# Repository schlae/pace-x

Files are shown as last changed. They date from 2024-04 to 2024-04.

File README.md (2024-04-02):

# Pace-X INS8900 Computer

(Still under development)

The INS8900 is a NMOS version of National Semiconductor's PACE microprocessor.
This was (probably) the first 16-bit microprocessor to hit the market in the
mid 1970s.

This is a very simple computer built around this chip. Features include

* 2MHz operation
* 128K words of RAM
* Up to 128K words of ROM
* 8250 (or compatible) UART
* Software controlled status LEDs
* 12VDC input

Note that the memory split between RROM and RAM is controlled by a PAL that
sets up the memory map. Banking is supported using up to three flag outputs
(F11, F12, F13) on the CPU. The current memory map is:

* 0000 to 001FF - ROM (can be swapped out with RAM using F11)
* 0200 to FDFF - RAM
* FE00 to FFFF - UART (mirrored a bunch of times)

UART access is easiest at FF00 (absolute). But it can also be done from the
zero page when BPS is brought high. This can be activated using F12.

The PAL code is assembled using `galette`. [site](https://github.com/simon-frankau/galette)

The assembly code for the INS8900 is assembled using `asl` [site]([http://john.ccac.rwth-aachen.de:8000/as/)

## Assembling the code

CPU source code is assembled as follows

```
asl test.asm -L
p2bin test.p test.bin
python3 split.py
```

The result are two files, `high.bin` and `low.bin` which need to be programmed
into two EPROMS or EEPROMS. You can do this with a TL866 using `minipro`. For example, using two MX28F1000P EEPROM chips:

```
minipro -p MX28F1000P -w low.bin -s
```
(swap the chips)
```
minipro -p MX28F1000P -w high.bin -s
```

To assemble and program the GAL, run
```
galette addr_decoder.pld
minipro -p ATF16V8B -w addr_decoder.jed
```

That's all for now!

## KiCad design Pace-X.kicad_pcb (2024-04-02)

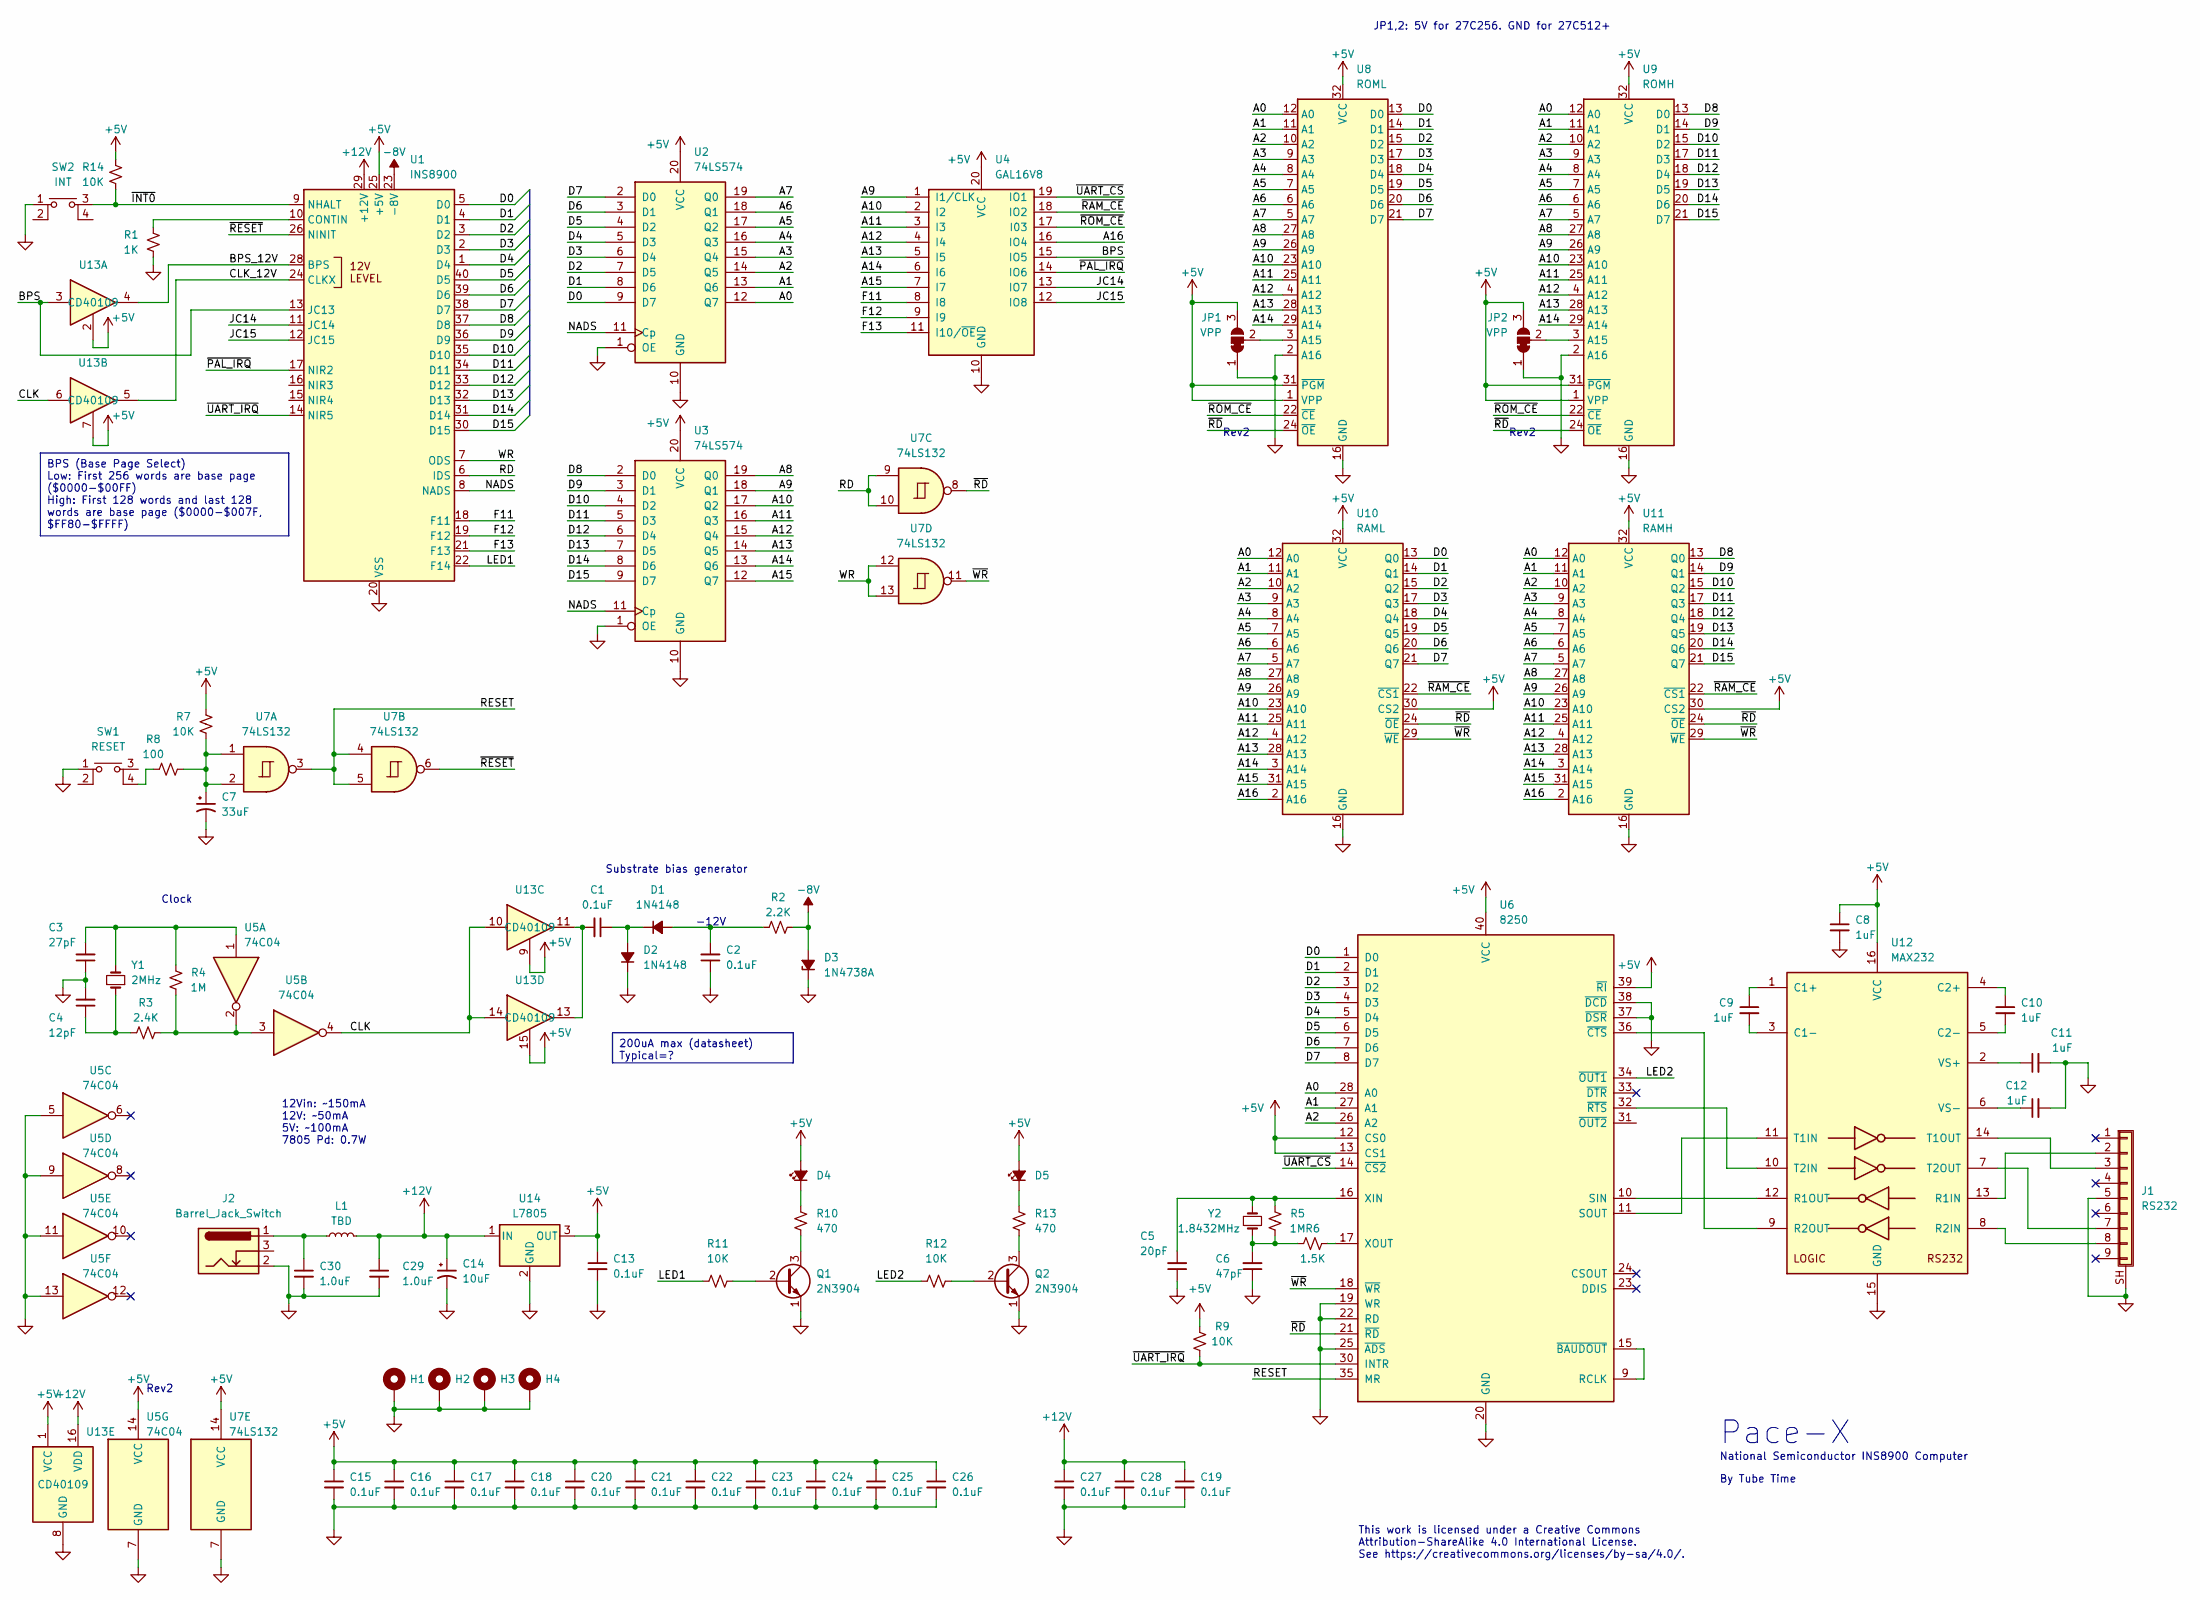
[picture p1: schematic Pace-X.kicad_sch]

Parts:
C1, C2, C13, C15, C16, C17, C18, C19, C20, C21, C22, C23, C24, C25, C26, C27, C28: 0.1uF; CAPAC200
C3: 27pF; CAPAC200
C4: 12pF; CAPAC200
C5: 20pF; CAPAC200
C6: 47pF; CAPAC200
C7: 33uF; CAPAE200P500X1100
C8, C9, C10, C11, C12: 1uF; CAPAC200
C14: 10uF; CAPAE200P500X1100
C29, C30: 1.0uF; CAPAC200
D1, D2: 1N4148; DIOA500
D3: 1N4738A; DIOA500
D4, D5: LED; LED_D5.0mm
H1, H2, H3, H4: MountingHole_Pad; MountingHole_3.2mm_M3_ISO7380_Pad
J1: RS232; DB9FC2
J2: Barrel_Jack_Switch; CUI_PJ-002B
JP1, JP2: VPP; SolderJumper-3_P1.3mm_Bridged12_RoundedPad1.0x1.5mm_NumberL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
L1: TBD; L_Axial_L7.0mm_D3.3mm_P12.70mm_Horizontal_Fastron_MICC
Q1, Q2: 2N3904; TO-92_Inline
R1: 1K; RESA500
R2: 2.2K; RESA500
R3: 2.4K; RESA500
R4, R5: 1M; RESA500
R6: 1.5K; RESA500
R7, R9, R11, R12, R14: 10K; RESA500
R8: 100; RESA500
R10, R13: 470; RESA500
SW1: RESET; ESWITCH_TL1105
SW2: INT; ESWITCH_TL1105
U1: INS8900; DIP254P1524X635-40
U2, U3: 74LS574; DIP254P762X635-20
U4: GAL16V8; DIP254P762X635-20
U5: 74C04; DIP254P762X635-14
U6: 8250; DIP254P1524X635-40
U7: 74LS132; DIP254P762X635-14
U8: ROML; DIP254P1524X635-32
U9: ROMH; DIP254P1524X635-32
U10: RAML; DIP254P1524X635-32
U11: RAMH; DIP254P1524X635-32
U12: MAX232; DIP254P762X635-16
U13: CD40109; DIP254P762X635-16
U14: L7805; TO-220-3_Horizontal_TabDown
Y1: 2MHz; Crystal_HC49-U_Vertical
Y2: 1.8432MHz; Crystal_HC49-U_Vertical

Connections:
-8V: D3.2 (A), R2.2, U1.23 (-8V)
/A0: U2.12 (Q7), U6.28 (A0), U8.12 (A0), U9.12 (A0), U10.12 (A0), U11.12 (A0)
/A1: U2.13 (Q6), U6.27 (A1), U8.11 (A1), U9.11 (A1), U10.11 (A1), U11.11 (A1)
/A2: U2.14 (Q5), U6.26 (A2), U8.10 (A2), U9.10 (A2), U10.10 (A2), U11.10 (A2)
/A3: U2.15 (Q4), U8.9 (A3), U9.9 (A3), U10.9 (A3), U11.9 (A3)
/A4: U2.16 (Q3), U8.8 (A4), U9.8 (A4), U10.8 (A4), U11.8 (A4)
/A5: U2.17 (Q2), U8.7 (A5), U9.7 (A5), U10.7 (A5), U11.7 (A5)
/A6: U2.18 (Q1), U8.6 (A6), U9.6 (A6), U10.6 (A6), U11.6 (A6)
/A7: U2.19 (Q0), U8.5 (A7), U9.5 (A7), U10.5 (A7), U11.5 (A7)
/A8: U3.19 (Q0), U8.27 (A8), U9.27 (A8), U10.27 (A8), U11.27 (A8)
/A9: U3.18 (Q1), U4.1 (I1/CLK), U8.26 (A9), U9.26 (A9), U10.26 (A9), U11.26 (A9)
/A10: U3.17 (Q2), U4.2 (I2), U8.23 (A10), U9.23 (A10), U10.23 (A10), U11.23 (A10)
/A11: U3.16 (Q3), U4.3 (I3), U8.25 (A11), U9.25 (A11), U10.25 (A11), U11.25 (A11)
/A12: U3.15 (Q4), U4.4 (I4), U8.4 (A12), U9.4 (A12), U10.4 (A12), U11.4 (A12)
/A13: U3.14 (Q5), U4.5 (I5), U8.28 (A13), U9.28 (A13), U10.28 (A13), U11.28 (A13)
/A14: U3.13 (Q6), U4.6 (I6), U8.29 (A14), U9.29 (A14), U10.3 (A14), U11.3 (A14)
/A15: U3.12 (Q7), U4.7 (I7), U10.31 (A15), U11.31 (A15)
/A16: U4.16 (IO4), U10.2 (A16), U11.2 (A16)
/BPS: U1.13 (JC13), U4.15 (IO5), U13.3
/BPS_12V: U1.28 (BPS), U13.4
/CLK: U5.4, U13.6, U13.10, U13.14
/CLK_12V: U1.24 (CLKX), U13.5
/D0: U1.5 (D0), U2.9 (D7), U6.1 (D0), U8.13 (D0), U10.13 (Q0)
/D1: U1.4 (D1), U2.8 (D6), U6.2 (D1), U8.14 (D1), U10.14 (Q1)
/D2: U1.3 (D2), U2.7 (D5), U6.3 (D2), U8.15 (D2), U10.15 (Q2)
/D3: U1.2 (D3), U2.6 (D4), U6.4 (D3), U8.17 (D3), U10.17 (Q3)
/D4: U1.1 (D4), U2.5 (D3), U6.5 (D4), U8.18 (D4), U10.18 (Q4)
/D5: U1.40 (D5), U2.4 (D2), U6.6 (D5), U8.19 (D5), U10.19 (Q5)
/D6: U1.39 (D6), U2.3 (D1), U6.7 (D6), U8.20 (D6), U10.20 (Q6)
/D7: U1.38 (D7), U2.2 (D0), U6.8 (D7), U8.21 (D7), U10.21 (Q7)
/D8: U1.37 (D8), U3.2 (D0), U9.13 (D0), U11.13 (Q0)
/D9: U1.36 (D9), U3.3 (D1), U9.14 (D1), U11.14 (Q1)
/D10: U1.35 (D10), U3.4 (D2), U9.15 (D2), U11.15 (Q2)
/D11: U1.34 (D11), U3.5 (D3), U9.17 (D3), U11.17 (Q3)
/D12: U1.33 (D12), U3.6 (D4), U9.18 (D4), U11.18 (Q4)
/D13: U1.32 (D13), U3.7 (D5), U9.19 (D5), U11.19 (Q5)
/D14: U1.31 (D14), U3.8 (D6), U9.20 (D6), U11.20 (Q6)
/D15: U1.30 (D15), U3.9 (D7), U9.21 (D7), U11.21 (Q7)
/F11: U1.18 (F11), U4.8 (I8)
/F12: U1.19 (F12), U4.9 (I9)
/F13: U1.21 (F13), U4.11 (I10/~OE)
/JC14: U1.11 (JC14), U4.13 (IO7)
/JC15: U1.12 (JC15), U4.12 (IO8)
/LED1: R11.2, U1.22 (F14)
/LED2: R12.2, U6.34 (~OUT1)
/NADS: U1.8 (NADS), U2.11 (Cp), U3.11 (Cp)
/RD: U1.6 (IDS), U7.9, U7.10
/RESET: U6.35 (MR), U7.3, U7.4, U7.5
/WR: U1.7 (ODS), U7.12, U7.13
/~INT0: R14.1, SW2.3, U1.9 (NHALT)
/~PAL_IRQ: U1.17 (NIR2), U4.14 (IO6)
/~RAM_CE: U4.18 (IO2), U10.22 (~CS1), U11.22 (~CS1)
/~RESET: U1.26 (NINIT), U7.6
/~ROM_CE: U4.17 (I03), U8.22 (~CE), U9.22 (~CE)
/~UART_CS: U4.19 (IO1), U6.14 (~CS2)
/~UART_IRQ: R9.1, U1.14 (NIR5), U6.30 (INTR)
/~WR: U6.18 (~WR), U7.11, U10.29 (~WE), U11.29 (~WE)
unnamed: C1.2, U13.11, U13.13
unnamed: C3.2, R4.1, U5.1, Y1.2
unnamed: C4.1, R3.1, Y1.1
unnamed: C7.1, R7.1, R8.1, U7.1, U7.2
unnamed: C30.1, J2.1, L1.1
unnamed: C2.2, D1.2 (A), R2.1
unnamed: C1.1, D1.1 (K), D2.2 (A)
unnamed: D4.1 (K), R10.1
unnamed: D5.1 (K), R13.1
unnamed: J1.2, U12.13 (R1IN)
unnamed: J1.3, U12.14 (T1OUT)
unnamed: J1.7, U12.7 (T2OUT)
unnamed: J1.8, U12.8 (R2IN)
unnamed: JP1.2 (C), U8.3 (A15)
unnamed: JP2.2 (C), U9.3 (A15)
unnamed: Q1.2 (B), R11.1
unnamed: Q1.3 (C), R10.2
unnamed: Q2.2 (B), R12.1
unnamed: Q2.3 (C), R13.2
unnamed: R3.2, R4.2, U5.2, U5.3
unnamed: R8.2, SW1.4
unnamed: R1.1, U1.10 (CONTIN)
unnamed: U6.9 (RCLK), U6.15 (~BAUDOUT)
unnamed: C5.2, R5.1, U6.16 (XIN), Y2.2
unnamed: C9.1, U12.1 (C1+)
unnamed: C9.2, U12.3 (C1-)
unnamed: C10.1, U12.4 (C2+)
unnamed: C10.2, U12.5 (C2-)
unnamed: U6.10 (SIN), U12.12 (R1OUT)
unnamed: U6.36 (~CTS), U12.9 (R2OUT)
unnamed: U6.11 (SOUT), U12.11 (T1IN)
unnamed: U6.32 (~RTS), U12.10 (T2IN)
unnamed: C11.1, U12.2 (VS+)
unnamed: C12.1, U12.6 (VS-)

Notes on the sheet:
BPS (Base Page Select) Low: First 256 words are base page ($0000-$00FF) High: First 128 words and last 128 words are base page ($0000-$007F, $FF80-$FFFF)
200uA max (datasheet) Typical=?
JP1,2: 5V for 27C256. GND for 27C512+
National Semiconductor INS8900 Computer
Rev2
12Vin: ~150mA 12V: ~50mA 5V: ~100mA 7805 Pd: 0.7W
Clock
Pace-X
-12V
Substrate bias generator
This work is licensed under a Creative Commons Attribution-ShareAlike 4.0 International License. See https://creativecommons.org/licenses/by-sa/4.0/.
By Tube Time

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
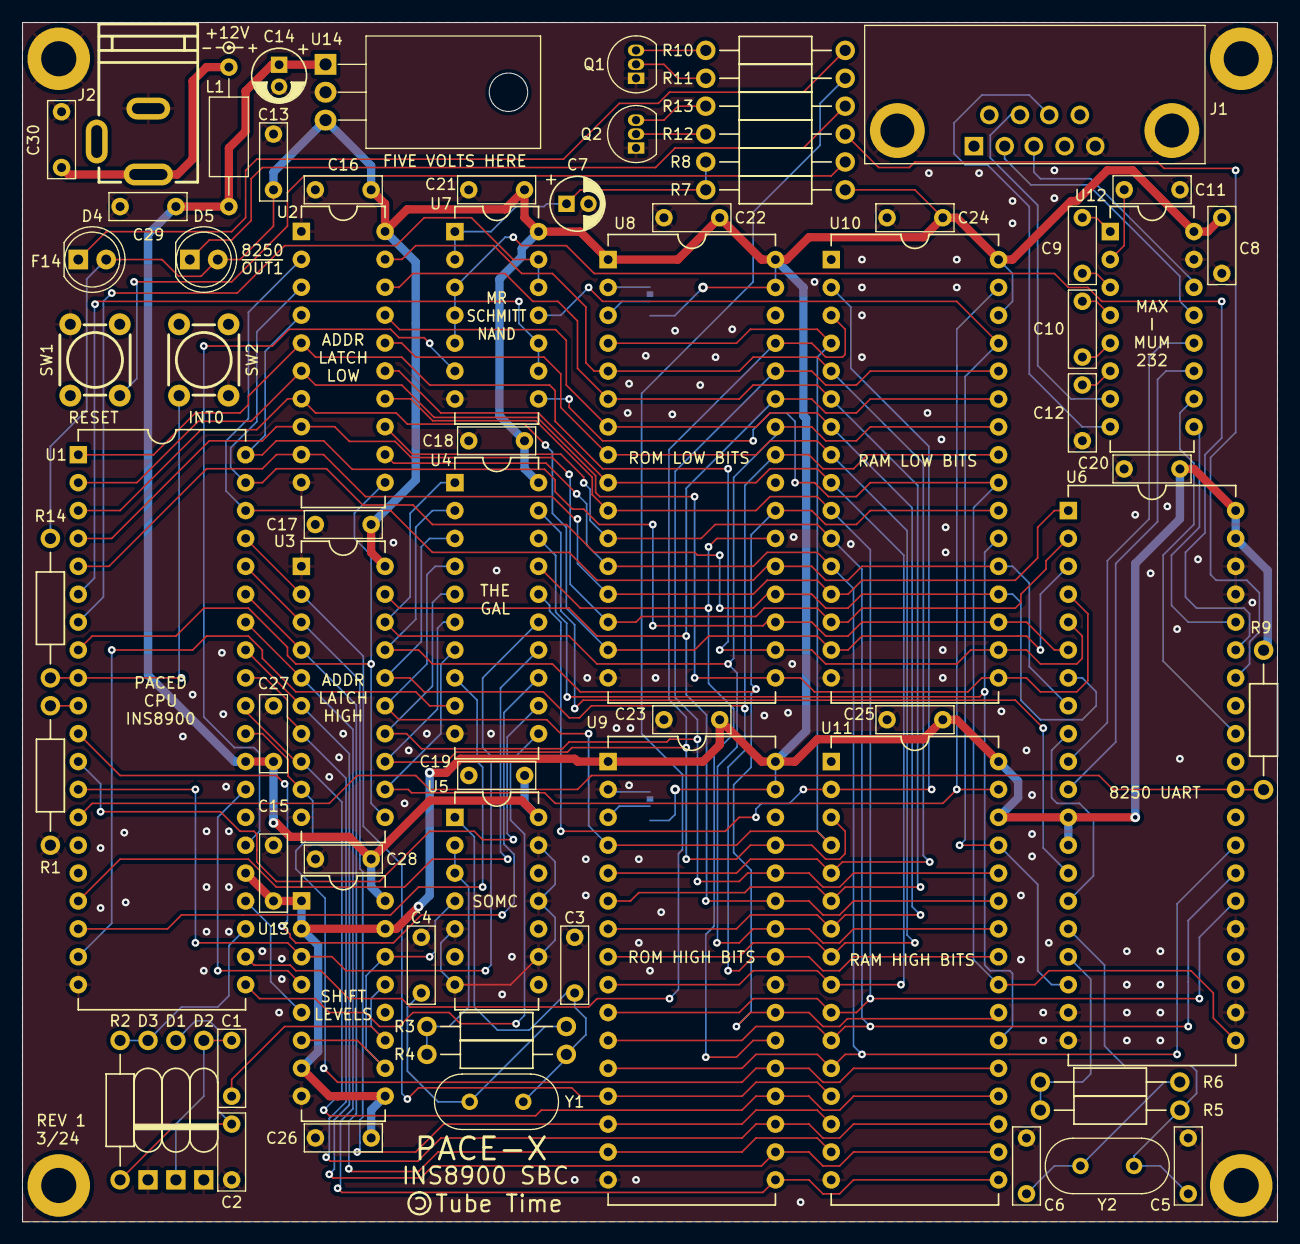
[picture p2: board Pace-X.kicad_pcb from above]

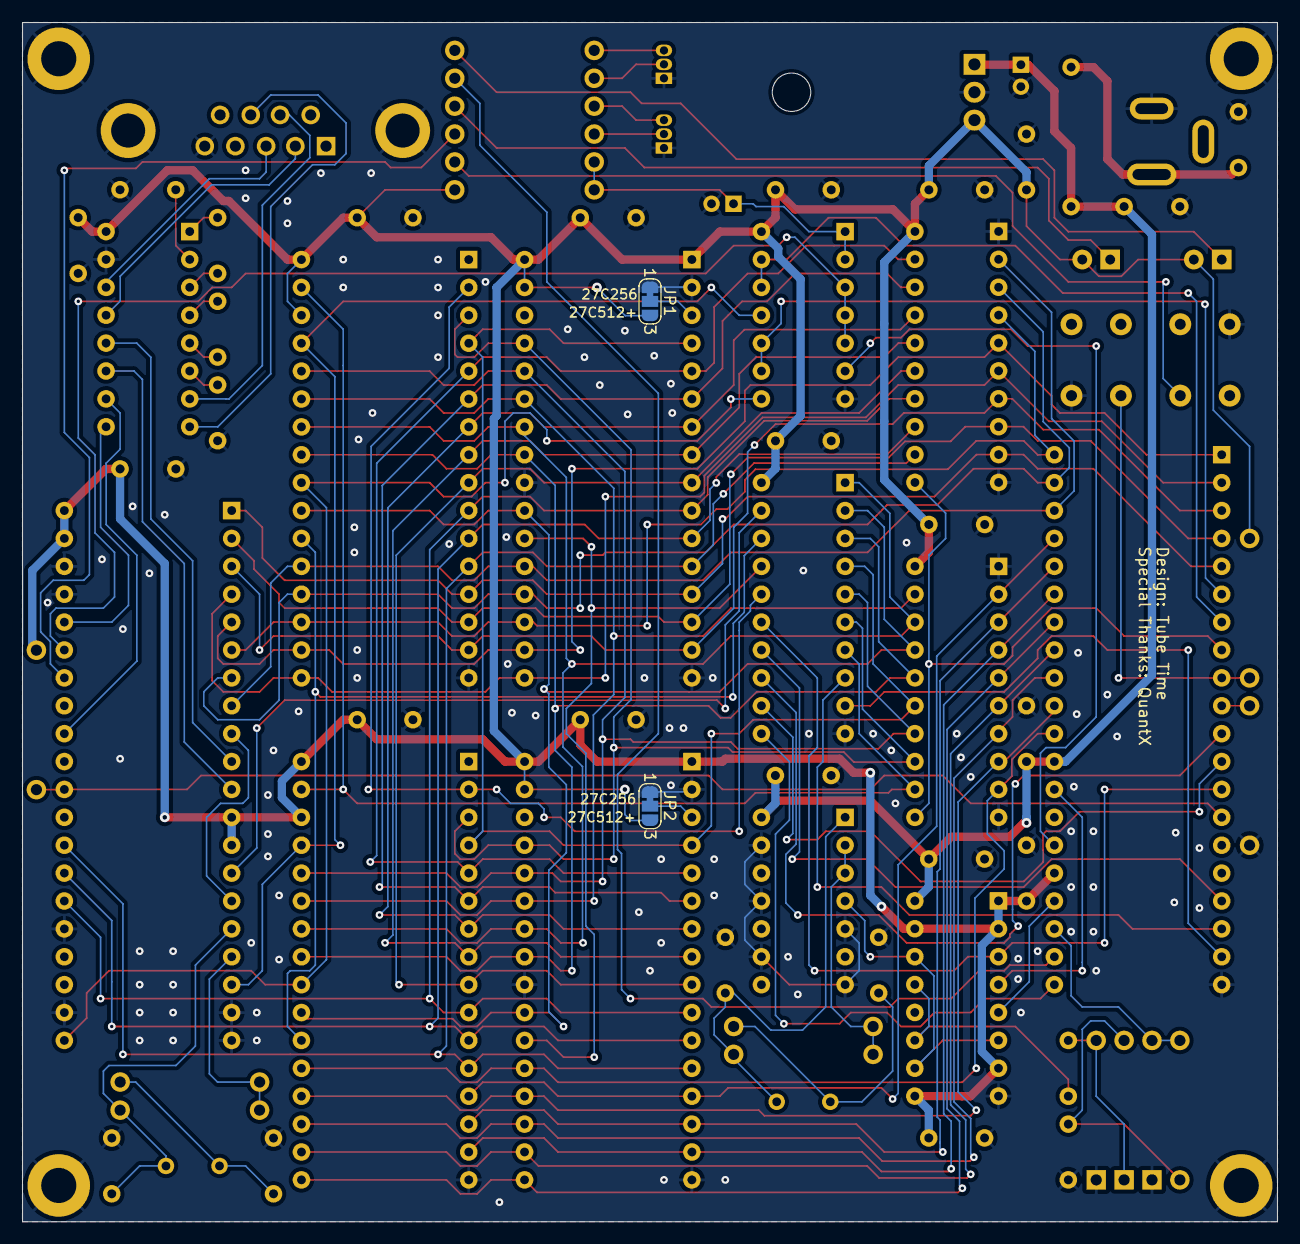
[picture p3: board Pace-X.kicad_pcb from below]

Board: 2 copper layers, 114.3 x 109.2 mm, 78 parts (2 on the bottom side), 97 nets.

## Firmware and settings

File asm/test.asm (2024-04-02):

    cpu INS8900

; Memory map
; 0000-01FF = ROM
; 0200-02FF = RAM
; FE00-FFFF = UART

    ORG 0
    JMP @tget
tget:
    DW main
    DW 1
    DW 2
    DW 3
    DW 4
    DW 5
    DW 6
    DW 7
ram_addr:
    DW x'0200'
uart_addr:
    DW x'FF00'
tmr_val:
    DW x'FF00'
greet_str_ptr:
    DW greet_str
greet_str:
    DW "Hello World!\r\n\0"
main:
    LI AC2, 0
    LD AC3, ram_addr
    LI AC1, x'7F'
    JSR copy_program ; Copy stuff to RAM
    JMP @sloc
sloc:
    DW x'0200' + now_in_ram
; Magic happens here
now_in_ram:
    SFLG F11 ; Map ROM out
    LD AC2, ram_addr
    LI AC3, 0
    LI AC1, x'7F'
    JSR copy_program ; Copy it back
    ; Prove that we edited it
    LI AC0, "Y"
    ST AC0, @greet_str_ptr
    JMP @sloc2 ; Make sure we go to absolute location
sloc2:
    DW actual_prog

; copy from AC2 to AC3
copy_program:
copyloop:
    LD AC0, 0(AC2)
    ST AC0, 0(AC3)
    AISZ AC2, 1
    NOP
    AISZ AC3, 1
    NOP
    AISZ AC1,-1
    JMP copyloop
    RTS 0

actual_prog:
    LD AC2, uart_addr
    LD AC3, ram_addr
    LD AC0, tmr_val
    SFLG BYTE
init_wait:
    AISZ AC0, 1
    JMP init_wait
uart_init:
    LD AC0, 5(AC2) ; Check LSR contents
    ; Throw away what we read.
    LI AC0, x'83'
    ST AC0, 3(AC2) ; line control reg, DLAB=1
    LI AC0, x'30'
    ST AC0, 0(AC2) ; divisor latch LS
    LI AC0, x'00'
    ST AC0, 1(AC2) ; divisor latch MS, set for 2400 baud
    LI AC0, x'03'  ; Use 8 bits.
    ST AC0, 3(AC2) ; line control reg, DLAB=0

do_again:
    LD AC3, greet_str_ptr
    JSR putstring
    JMP do_again

; AC3 points to string
putstring:
stringloop:
    LD AC0, 0(AC3)
    BOC REQ0, endstring
    JSR putchar
    AISZ AC3, 1
    NOP
    RCPY AC3, AC0 ; Copy AC3 to AC0
    SHR AC0, 2
    PFLG F14
    BOC BIT0, skpled
    SFLG F14
skpled:
    JMP stringloop
endstring:
    RTS 0

; AC0 is character. AC2 is address of UART
putchar:
    ST AC0, 0(AC2) ; transmit holding register
    LD AC1, tmr_val ; timeout
    ; Now wait for transmit to complete
checkloop:
    LD AC0, 5(AC2) ; line status register, check bit 5
    SHR AC0, 5
    BOC BIT0, success ; transmit next byte if ready
    ;AISZ AC1, x'01' ; try again until we time out
    JMP checkloop
    RTS 0; TODO: fail code?
success:
    RTS 0
